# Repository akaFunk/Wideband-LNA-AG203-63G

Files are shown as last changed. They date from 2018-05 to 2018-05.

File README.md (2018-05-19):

# Wideband LNA AG203-63G
The Qorvo AG203-63G [1] is a cheap amplifier with (quite) low noise and very high bandwidth. The noise figure is roughly 3 dB, gain is around 20 dB and it works from DC to 6 GHz. It does not reuqire external matching, thus the schematic is very simple.

The PCB has a height of 0.6 mm, which is crucial (at least at higher frequencies) and it was ordered in China [2]. The populated PCB was soldered into a tinplate filter housing FG1 of size 37x20x20 mm [3]. To get the DC voltage into the housing a 1000 pF feed through capacitor DF 38 [4] was used.

The fully build amplifier has been characterized using an DG8SAQ VNA [5]. The input return loss is ca. 15 dB for 70 cm band (433 MHz) and ca. 21 dB for 2 m band (145 MHz). The data of the measurement can be found in the measurements folder. When you want to operate the LNA at a higher frequency, you should replace the coupling capacitors C1 and C3 and the feed inductor L1 with smaller values. See the datasheet [1] for details.

## Images
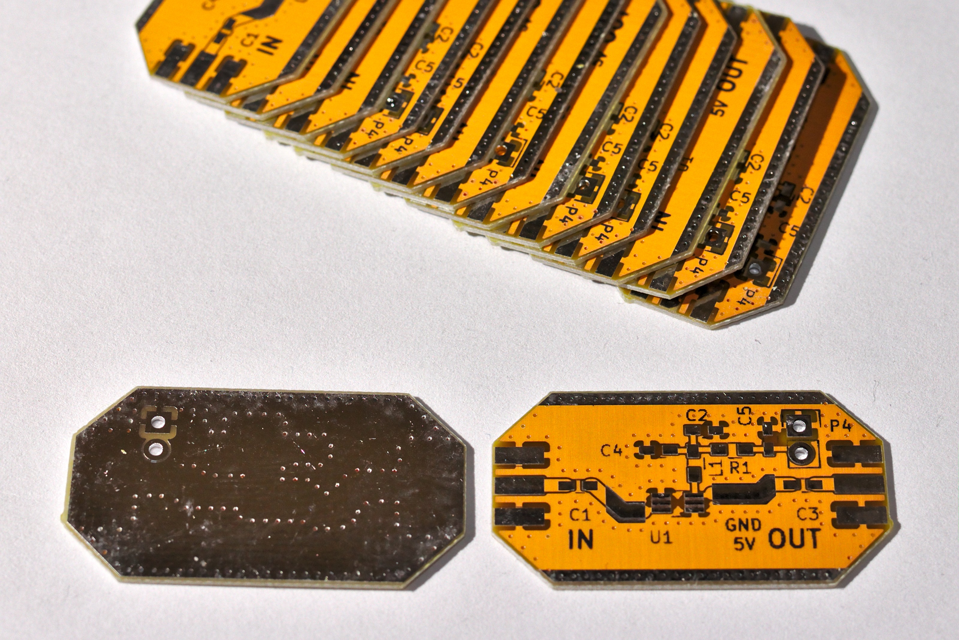
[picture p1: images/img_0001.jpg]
PCB from China

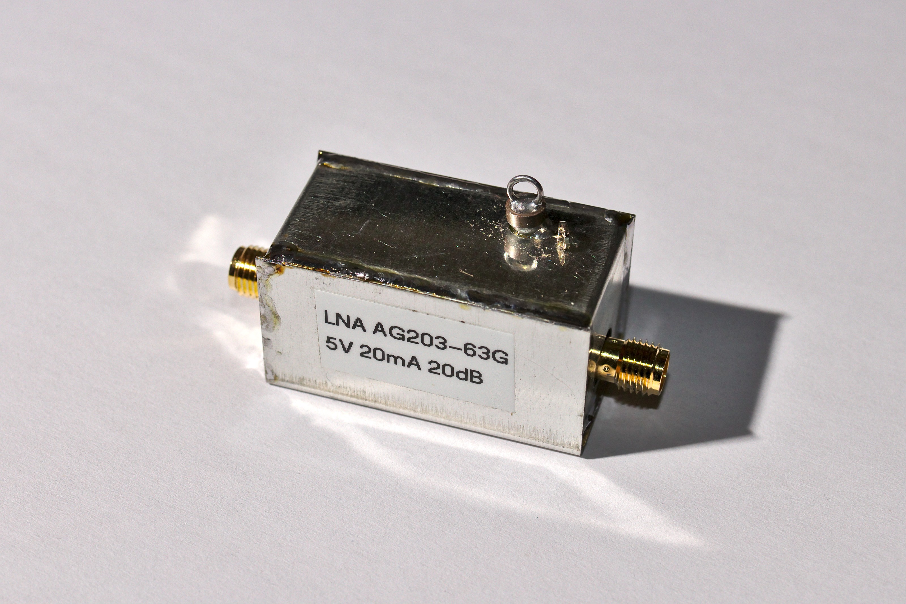
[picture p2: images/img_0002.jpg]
Finished LNA in the tinplated housing

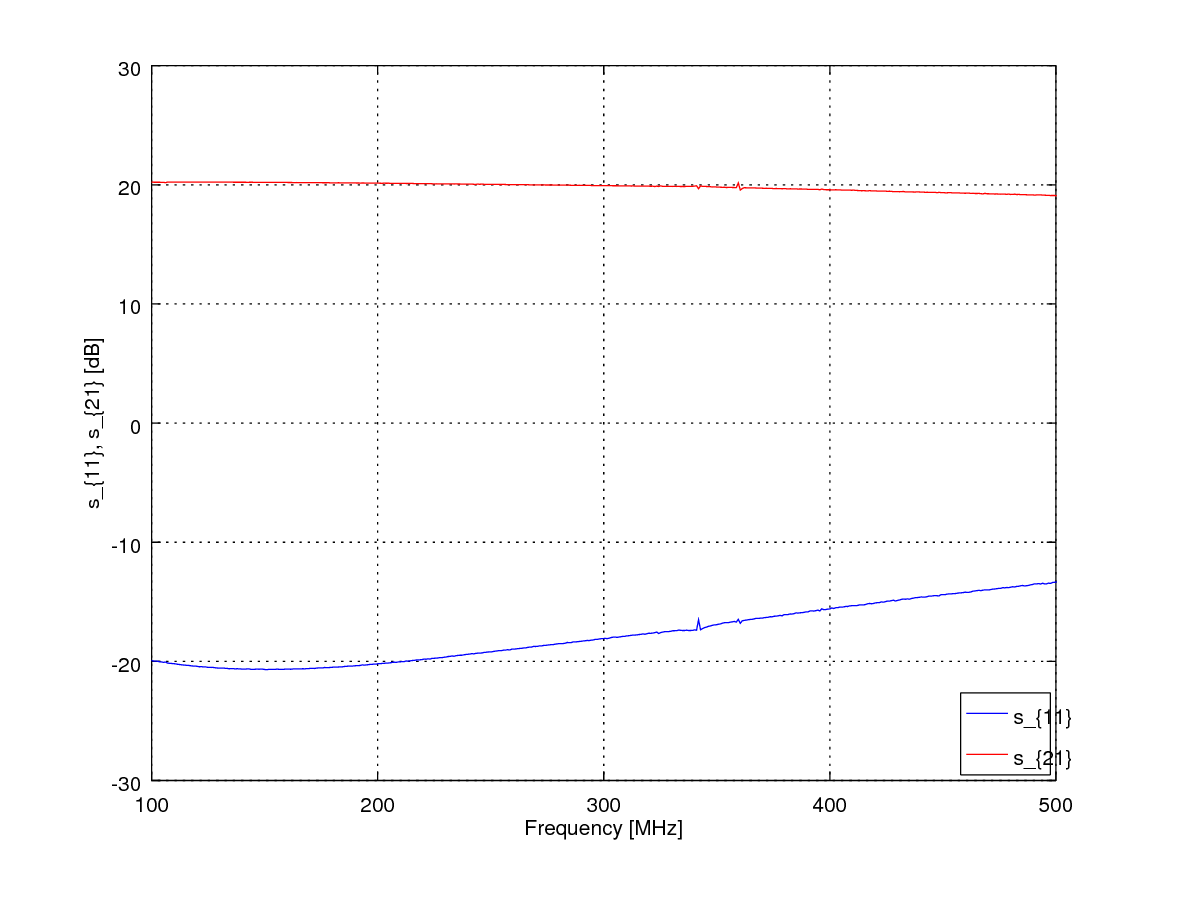
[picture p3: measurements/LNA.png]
S-Parameter measurement


## References
[1] https://www.qorvo.com/products/p/AG203-63G  
[2] http://www.elecrow.com  
[3] http://www.schubert-gehaeuse.de/prod01.htm  
[4] http://www.oppermann-electronic.de/html/durchf__c_s.html  
[5] https://www.sdr-kits.net/introducing-DG8SAQ-VNWA3

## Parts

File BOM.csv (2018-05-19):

Reference | Quantity | Value | MPN
P1 | 1 | RF1 | 2579819
P3 | 1 | RF2 | 2579819
C1;C3;C4;C2 | 4 | 10n | C0603X103J3JACAUTO
C5 | 1 | 100n | C0603X104J3RACTU
P4 | 1 | VC1
U1 | 1 | AG203-63G | AG203-63G
L1 | 1 | 470n | L-14WR47JV4E
R1 | 1 | 47

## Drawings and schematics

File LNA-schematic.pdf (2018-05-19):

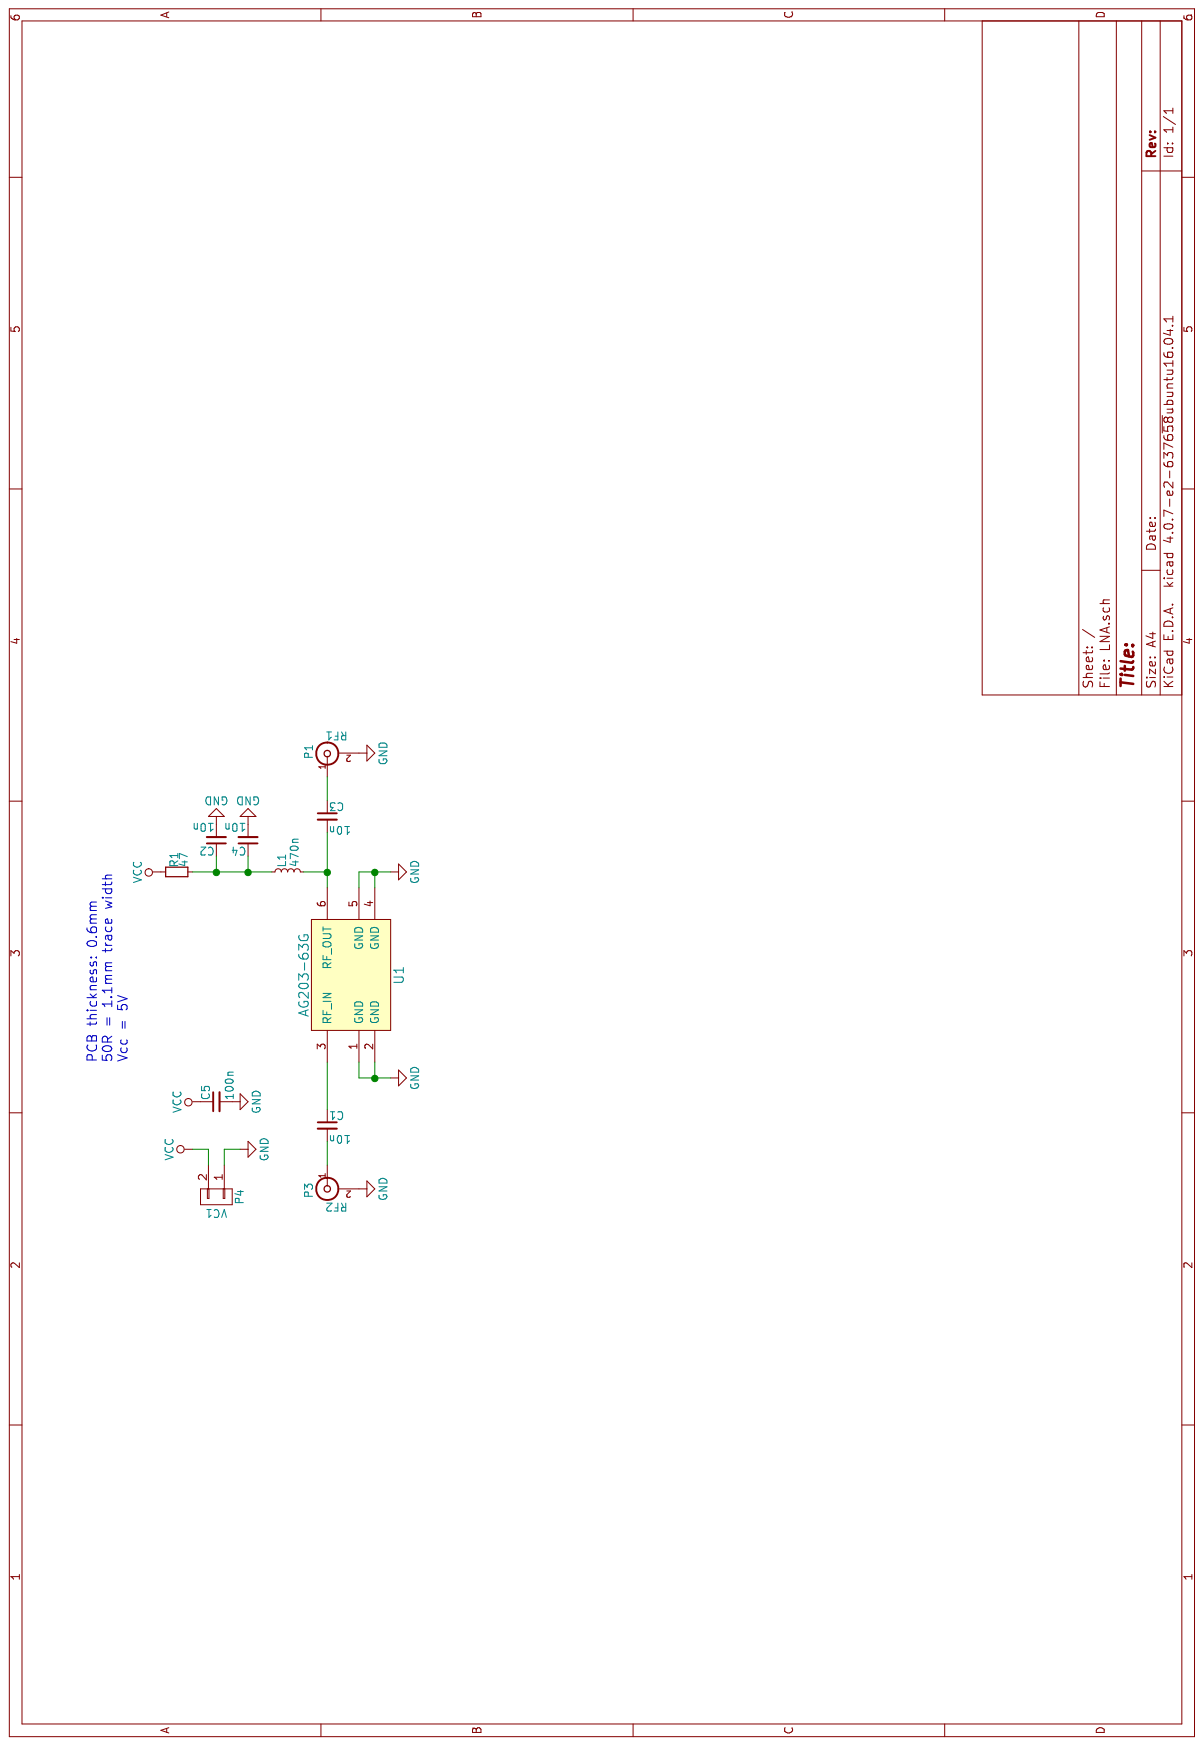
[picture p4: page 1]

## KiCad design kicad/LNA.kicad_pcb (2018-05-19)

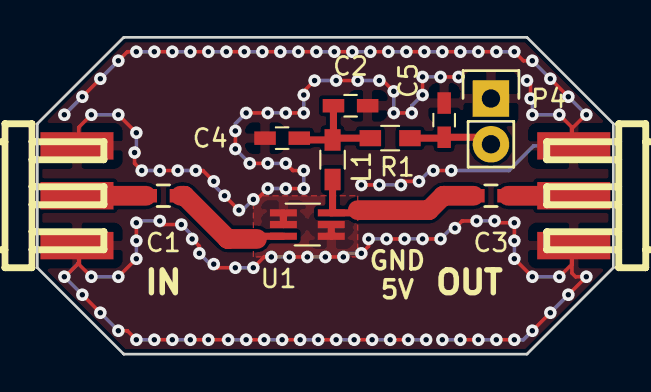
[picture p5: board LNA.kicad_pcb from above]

Board: 2 copper layers, 32.0 x 17.6 mm, 11 parts (0 on the bottom side), 7 nets.

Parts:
C1, C2, C3, C4: 10n; C_0603_HandSoldering
C5: 100n; C_0603_HandSoldering
L1: 470n; L_0603_HandSoldering
P1: OUT; CON-SMA-EDGE
P3: IN; CON-SMA-EDGE
P4: VC1; Pin_Header_Straight_1x02
R1: 47.5; R_0603_HandSoldering
U1: AG203-63G; SOT-363_SC-70-6_Handsoldering

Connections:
GND: C2.2, C4.2, C5.2, P1.2, P3.2, P4.1, U1.1, U1.2, U1.4, U1.5
unnamed: C1.1, U1.3
unnamed: C1.2, P3.1
unnamed: C2.1, C4.1, L1.1, R1.2
unnamed: C3.1, P1.1
unnamed: C3.2, L1.2, U1.6
VCC: C5.1, P4.2, R1.1
